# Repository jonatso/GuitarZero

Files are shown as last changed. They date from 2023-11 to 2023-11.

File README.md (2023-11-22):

## The idea

Our concept was a game inspired by Guitar Hero, where the player plays notes corresponding with notes ”falling down” a led matrix. Whether or not the player successfully plays the beat, determines which notes are actually being played. The player is meant to control the lead instrument, resulting in this instrument not being played whenever the player fails to hit a note. The backing instruments are always played. From the menu, the player has the option to select between a handful of songs of varying difficulty.

## Technical Summary

The MCU controls the song flow, input from the user and the visual output. The MCU sends data over SPI to the FPGA containing the required information about which notes the FPGA should play. The FPGA receives this data, and generates an audio signal using a set of pre-made instruments which contain one or more voices. This signal is further passed on to a DAC using I2S. Finally, the DAC outputs the audio to the onboard speaker or the audio jack.

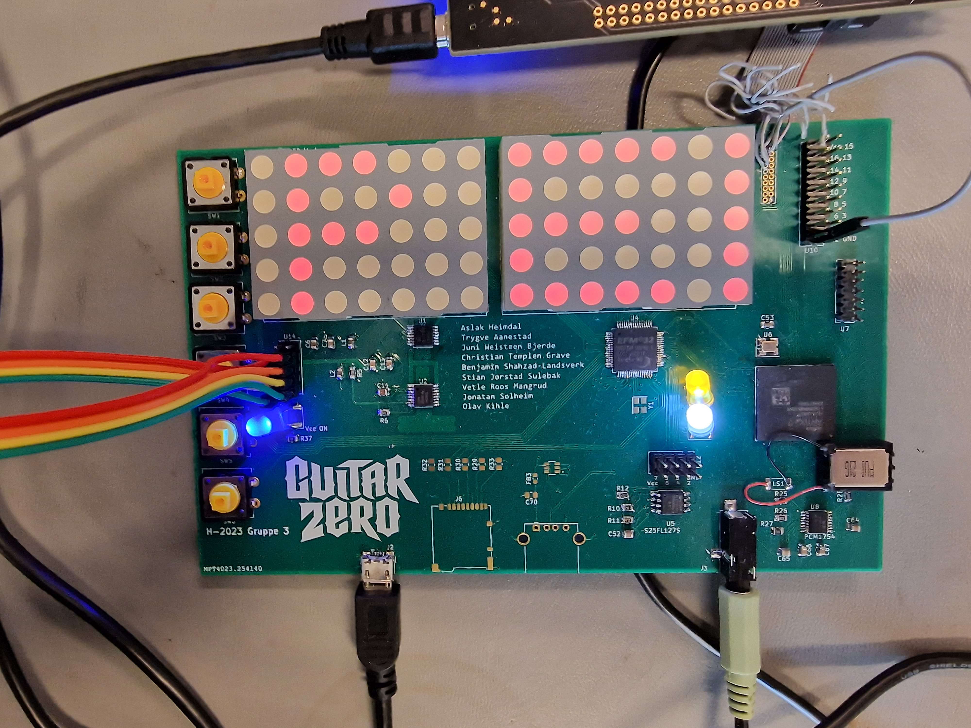
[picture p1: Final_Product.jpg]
Final Product


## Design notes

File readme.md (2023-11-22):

# GUITAR ZEEROOOOO MCU PROJECT

Bare minimum example, schmekket fra eksempelene:
- [USB Host Enum](https://github.com/EnergyMicro/EFM32GG_STK3700/tree/master/examples/usbhenum)
- [USB Host kbd](https://github.com/EnergyMicro/EFM32WG_DK3850/blob/master/examples/usbhhidkbd)

## Setup

- bruk linux eller WSL dings
- clone repoet
- i en annen dir, clone gecko sdk-en: [Gecko SDK](https://github.com/SiliconLabs/gecko_sdk), eller bare kopier hele sdk-en
- gå til cmake/GuitarZeroMCU.cmake og endre SDK_PATH til forrige step

## REQUIREMENTS

### ARM gcc toolchain
arm-none-eabi toolchain lagt til som binary executable i /usr/bin
- Last ned tarballen for linux [HER](https://launchpad.net/gcc-arm-embedded/+download) (jeg la den i /tmp)

```sh
# jeg pakket ut i /usr/share
sudo tar xjf gcc-arm-none-eabi-YOUR-VERSION.bz2 -C /usr/share/

# lager symolic links fra executablene til /usr/bin
sudo ln -s /usr/share/gcc-arm-none-eabi-YOUR-VERSION/bin/arm-none-eabi-gcc /usr/bin/arm-none-eabi-gcc 
sudo ln -s /usr/share/gcc-arm-none-eabi-YOUR-VERSION/bin/arm-none-eabi-g++ /usr/bin/arm-none-eabi-g++
sudo ln -s /usr/share/gcc-arm-none-eabi-YOUR-VERSION/bin/arm-none-eabi-gdb /usr/bin/arm-none-eabi-gdb
sudo ln -s /usr/share/gcc-arm-none-eabi-YOUR-VERSION/bin/arm-none-eabi-size /usr/bin/arm-none-eabi-size
sudo ln -s /usr/share/gcc-arm-none-eabi-YOUR-VERSION/bin/arm-none-eabi-objcopy /usr/bin/arm-none-eabi-objcopy
sudo ln -s /usr/share/gcc-arm-none-eabi-YOUR-VERSION/bin/arm-none-eabi-gcc-ranlib /usr/bin/arm-none-eabi-gcc-ranlib
sudo ln -s /usr/share/gcc-arm-none-eabi-YOUR-VERSION/bin/arm-none-eabi-ar /usr/bin/arm-none-eabi-ar

# check at de er lagt til i pathen
arm-none-eabi-gcc --version
arm-none-eabi-g++ --version
arm-none-eabi-gdb --version
arm-none-eabi-size --version
# osv ...
```

### CMAKE 3.25 eller nyere (Jeg brukte 3.27.7)
Man får ikke de nyere versjonene av Cmake med apt eller apt-get, så måtte installere manuelt. 
Jeg brukte denne guiden [HER](https://graspingtech.com/upgrade-cmake/), men den var meget slow...

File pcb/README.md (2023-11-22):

# TDT4295

Open GuitarZero.kicad_pro in kicad to open the projetc. Then click schematic ceditor to view the schematic.
Seperate schematic files for FPGA, PSU, MCU and DAC can be opened directly or via the GuitarZero.sch file.

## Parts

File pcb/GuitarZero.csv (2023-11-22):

Id | Designator | Footprint | Quantity | Designation | Supplier and ref
1 | FB3,FB1 | L_0603_1608Metric | 2 | FerriteBead
2 | J1 | USB_A_Stewart_SS-52100-001_Horizontal | 1 | USB_A
3 | C13,C7,C6,C12,C16,C73,C17 | C_0805_2012Metric | 7 | 22u
4 | J3 | Jack_3.5mm_CUI_SJ-3524-SMT_Horizontal | 1 | AudioJack3_SwitchT
5 | J6 | microSD_HC_Hirose_DM3BT-DSF-PEJS | 1 | Micro_SD_Card_Det_Hirose_DM3AT
6 | C11,C52,C53,C72,C55,C57,C5,C10,C59,C15,C19,C2,C60 | C_0805_2012Metric | 13 | 100n
7 | R29,R30,R27,R26,R25,R31,R28 | R_0805_2012Metric | 7 | 22
8 | D1,D2,D4 | LED_1812_4532Metric | 3 | LED
9 | J2 | USB_Micro-B_Amphenol_10103594-0001LF_Horizontal | 1 | USB_B_Micro
10 | U14 | PinHeader_2x05_P2.54mm_Vertical | 1 | Power_Jumpers
11 | U6 | Oscillator_SMD_Abracon_ASE-4Pin_3.2x2.5mm_HandSoldering | 1 | Oscillator
12 | C65,C66,C67,C64,C54,C9,C61,C58,C1,C18 | C_0805_2012Metric | 10 | 10u
13 | C70,C3,C35 | C_0805_2012Metric | 3 | 100u
14 | U3 | Xilinx_FTG256 | 1 | XC7A100T-FTG256
15 | SW3,SW2,SW6,SW5,SW1,SW4 | SW_CW_GPTS203211B | 6 | SW_Push
16 | R10 | R_0805_2012Metric | 1 | 2.4k
17 | U8 | SOP63P599X175-16N | 1 | PCM1754
18 | L1,L2 | L_0805_2012Metric | 2 | 1.5u
19 | J4 | PinSocket_2x10_P1.27mm_Vertical | 1 | MCU_Debug
20 | U5 | SOIC-8W_5.3x5.3mm_P1.27mm | 1 | S25FL127S
21 | U11,U13 | LED_TA20-11SRWA | 2 | 5x7 LED_matrix
22 | U4 | TQFP-64_10x10mm_P0.5mm | 1 | EFM32GG332
23 | Y1 | Crystal_SMD_Abracon_ABM8G-4Pin_3.2x2.5mm | 1 | Crystal_GND23
24 | R12,R11,R16,R15 | R_0805_2012Metric | 4 | 4.7k
25 | R5 | R_0805_2012Metric | 1 | 30.1k
26 | R37,R17,R34,R35 | R_0805_2012Metric | 4 | 330
27 | R33,R32 | R_0805_2012Metric | 2 | 47k
28 | R6,R8,R4 | R_0805_2012Metric | 3 | 22.1k
29 | U7 | PinSocket_2x07_P2.00mm_Vertical | 1 | FPGA_JTAG_Debug
30 | U9 | SOT95P280X145-6N | 1 | TPD_Current_Switch
31 | U2 | HTSSOP-16-1EP_4.4x5mm_P0.65mm_EP3x3mm | 1 | TSP54294
32 | LS1 | R_2010_5025Metric | 1 | Speaker
33 | U1 | TSSOP-14-1EP_4.4x5mm_P0.65mm | 1 | TPS54325
34 | U10 | PinHeader_2x09_P2.54mm_Vertical | 1 | FPGA_GPIO_Extra
35 | U12 | PinHeader_2x04_P2.54mm_Vertical | 1 | MCU_GPIO_Extra
36 | C31,C37,C30,C36,C51,C41,C34,C32,C33,C50,C42,C43,C29,C27,C49,C48,C28 | C_0603_1608Metric | 17 | 0.47u
37 | R1,R2 | R_0805_2012Metric | 2 | 100k
38 | R24,R21,R18,R23,R22 | R_0805_2012Metric | 5 | 100
39 | C56,C71,C4,C14 | C_0805_2012Metric | 4 | 1u
40 | R14,R13 | R_0805_2012Metric | 2 | 10k
41 | R3 | R_0805_2012Metric | 1 | 6.81k
42 | C24,C40,C23,C26,C47,C25,C22,C46,C21,C39 | C_0805_2012Metric | 10 | 4.7u
43 | C68,C69,C62,C63 | C_0805_2012Metric | 4 | 10n
44 | C45,C38,C44 | C_0805_2012Metric | 3 | 47u
45 | R7 | R_0805_2012Metric | 1 | 73.2k
46 | C20 | CAPMP7.6X4.3_1.9N_KEM | 1 | 330u
47 | R19,R20 | R_0805_2012Metric | 2 | 15
48 | R9 | R_0805_2012Metric | 1 | 1
49 | L3 | L_0805_2012Metric | 1 | 2.2u
50 | C8 | C_0805_2012Metric | 1 | 3.3n

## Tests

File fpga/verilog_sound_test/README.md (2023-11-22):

The files in this folder were used during the intial testing of the sound generating modules, before we started to use Vidado and a real FGPA. Many of the modules have been modified later, and is updated in the Vivado project files.
1. Install icarus-verilog (```brew install icarus-verilog``` for mac) + Python
2. ```pip install -r requirements.txt```
3. ```./run.sh```
4. ```./run_amplitude.sh```
5. ```./run_instrument.sh```

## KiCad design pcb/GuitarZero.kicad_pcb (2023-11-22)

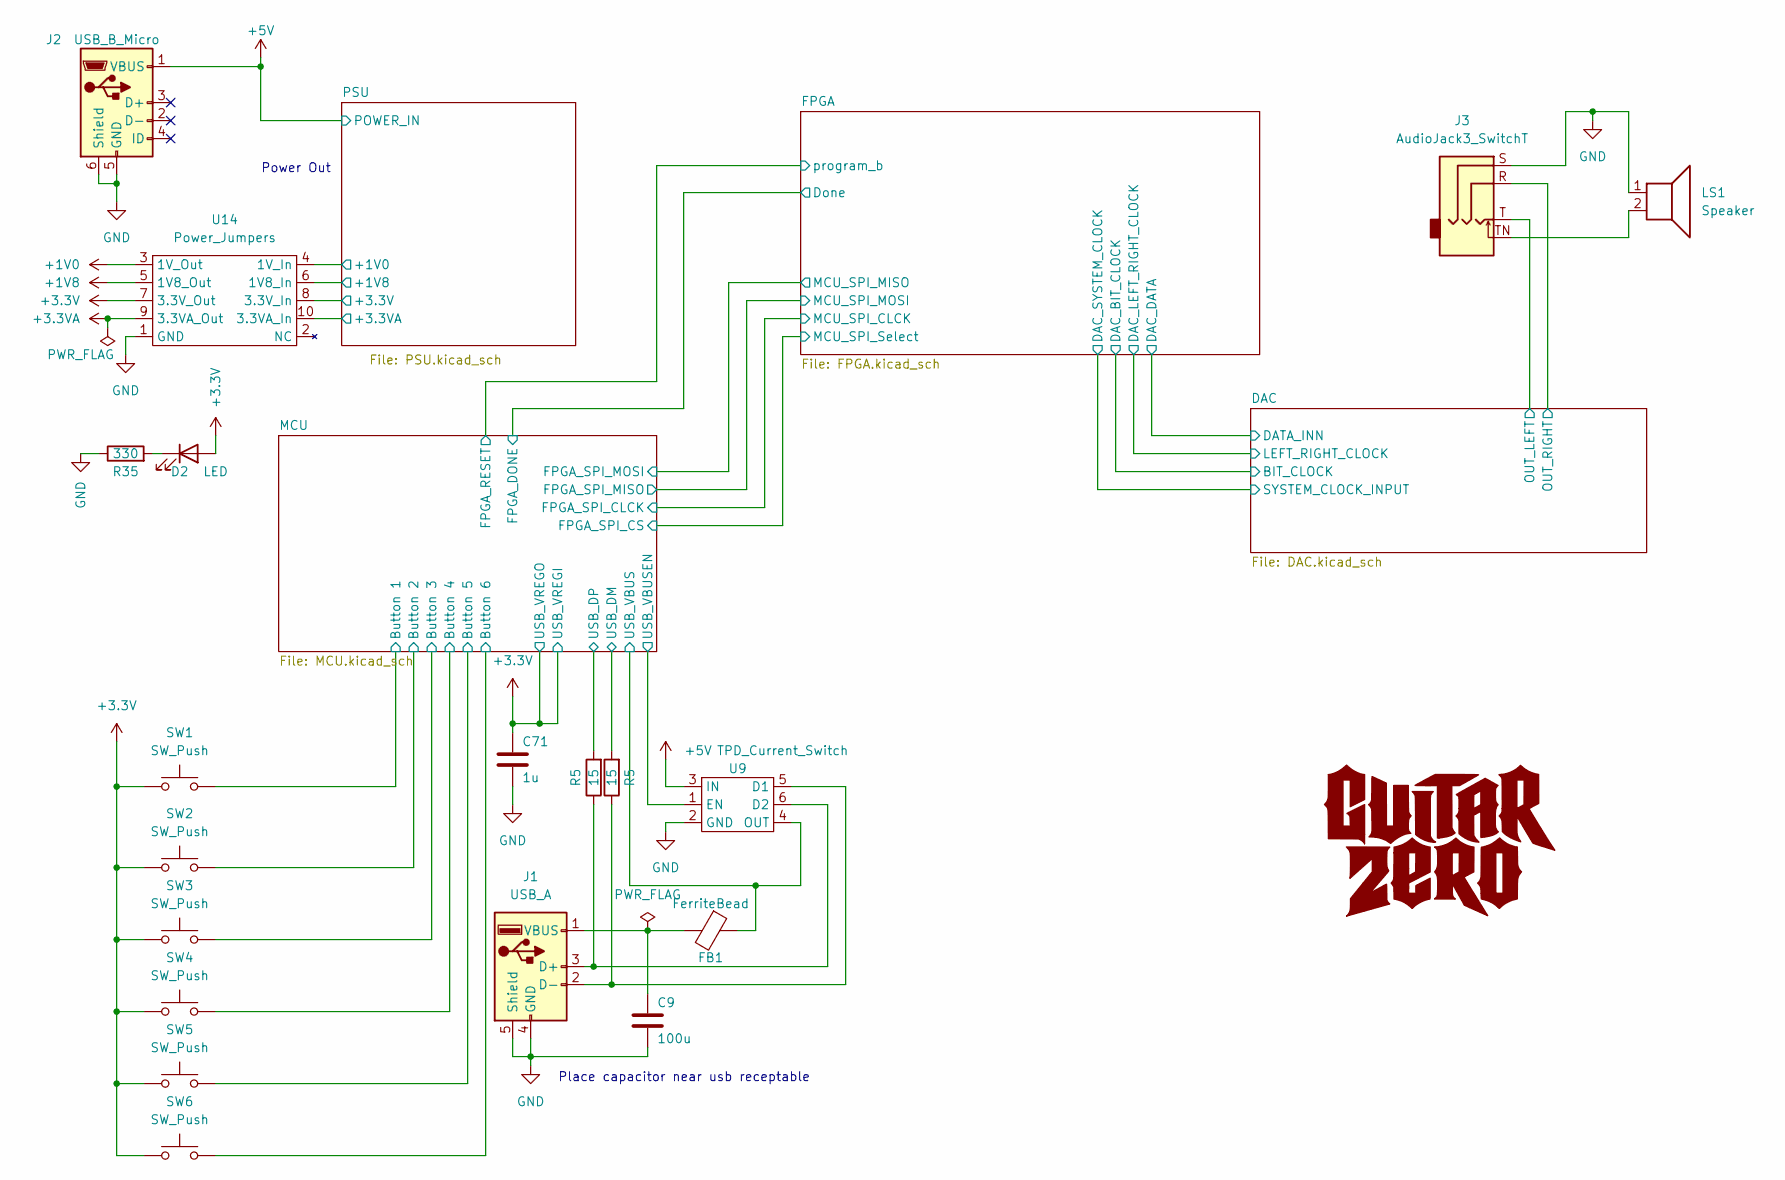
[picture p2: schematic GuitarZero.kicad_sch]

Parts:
C9: 100u; C_0805_2012Metric
C71: 1u; C_0805_2012Metric
D2: LED; LED_1812_4532Metric
FB1: FerriteBead; L_0603_1608Metric
J1: USB_A; USB_A_Stewart_SS-52100-001_Horizontal
J2: USB_B_Micro; USB_Micro-B_Amphenol_10103594-0001LF_Horizontal
J3: AudioJack3_SwitchT; Jack_3.5mm_CUI_SJ-3524-SMT_Horizontal
LS1: Speaker; R_2010_5025Metric
R5: 15; R_0805_2012Metric
R35: 330; R_0805_2012Metric
SW1, SW2, SW3, SW4, SW5, SW6: SW_Push; SW_CW_GPTS203211B
U9: TPD_Current_Switch; SOT95P280X145-6N
U14: Power_Jumpers; PinHeader_2x05_P2.54mm_Vertical

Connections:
+1V0: U14.3 (1V_Out); also elsewhere on the board
+1V8: U14.5 (1V8_Out); also elsewhere on the board
/DAC/OUT_LEFT: J3.T; also elsewhere on the board
/DAC/OUT_RIGHT: J3.R; also elsewhere on the board
/MCU/Button 1: SW1.2; also elsewhere on the board
/MCU/Button 2: SW2.2; also elsewhere on the board
/MCU/Button 3: SW3.2; also elsewhere on the board
/MCU/Button 4: SW4.2; also elsewhere on the board
/MCU/Button 5: SW5.2; also elsewhere on the board
/MCU/Button 6: SW6.2; also elsewhere on the board
/MCU/USB_VBUSEN: U9.1 (EN); also elsewhere on the board
/PSU/+1V0: U14.4 (1V_In); also elsewhere on the board
/PSU/+1V8: R5.2, U14.6 (1V8_In); also elsewhere on the board
/PSU/+3.3VA: U14.10 (3.3VA_In); also elsewhere on the board
unnamed: D2.1 (K), R35.2
unnamed: J3.TN, LS1.2

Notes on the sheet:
Power Out
Place capacitor near usb receptable

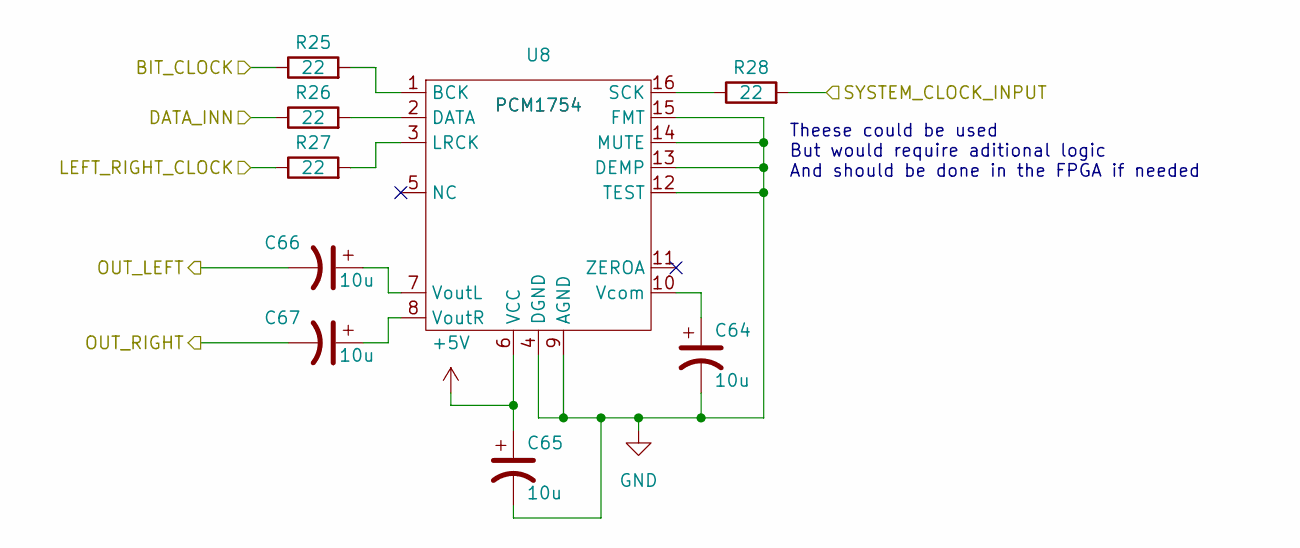
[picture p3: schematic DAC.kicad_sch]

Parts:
C64, C65, C66, C67: 10u; C_0805_2012Metric
R25, R26, R27, R28: 22; R_0805_2012Metric
U8: PCM1754; SOP63P599X175-16N

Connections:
/DAC/BIT_CLOCK: R25.1; also elsewhere on the board
/DAC/DATA_INN: R26.1; also elsewhere on the board
/DAC/LEFT_RIGHT_CLOCK: R27.1; also elsewhere on the board
/DAC/OUT_LEFT: C66.2; also elsewhere on the board
/DAC/OUT_RIGHT: C67.2; also elsewhere on the board
/DAC/SYSTEM_CLOCK_INPUT: R28.2; also elsewhere on the board
unnamed: R25.2, U8.1 (BCK)
unnamed: R26.2, U8.2 (DATA)
unnamed: R27.2, U8.3 (LRCK)
unnamed: R28.1, U8.16 (SCK)
unnamed: C64.1, U8.10 (Vcom)
unnamed: C66.1, U8.7 (VoutL)
unnamed: C67.1, U8.8 (VoutR)

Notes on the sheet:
Theese could be used But would require aditional logic And should be done in the FPGA if needed

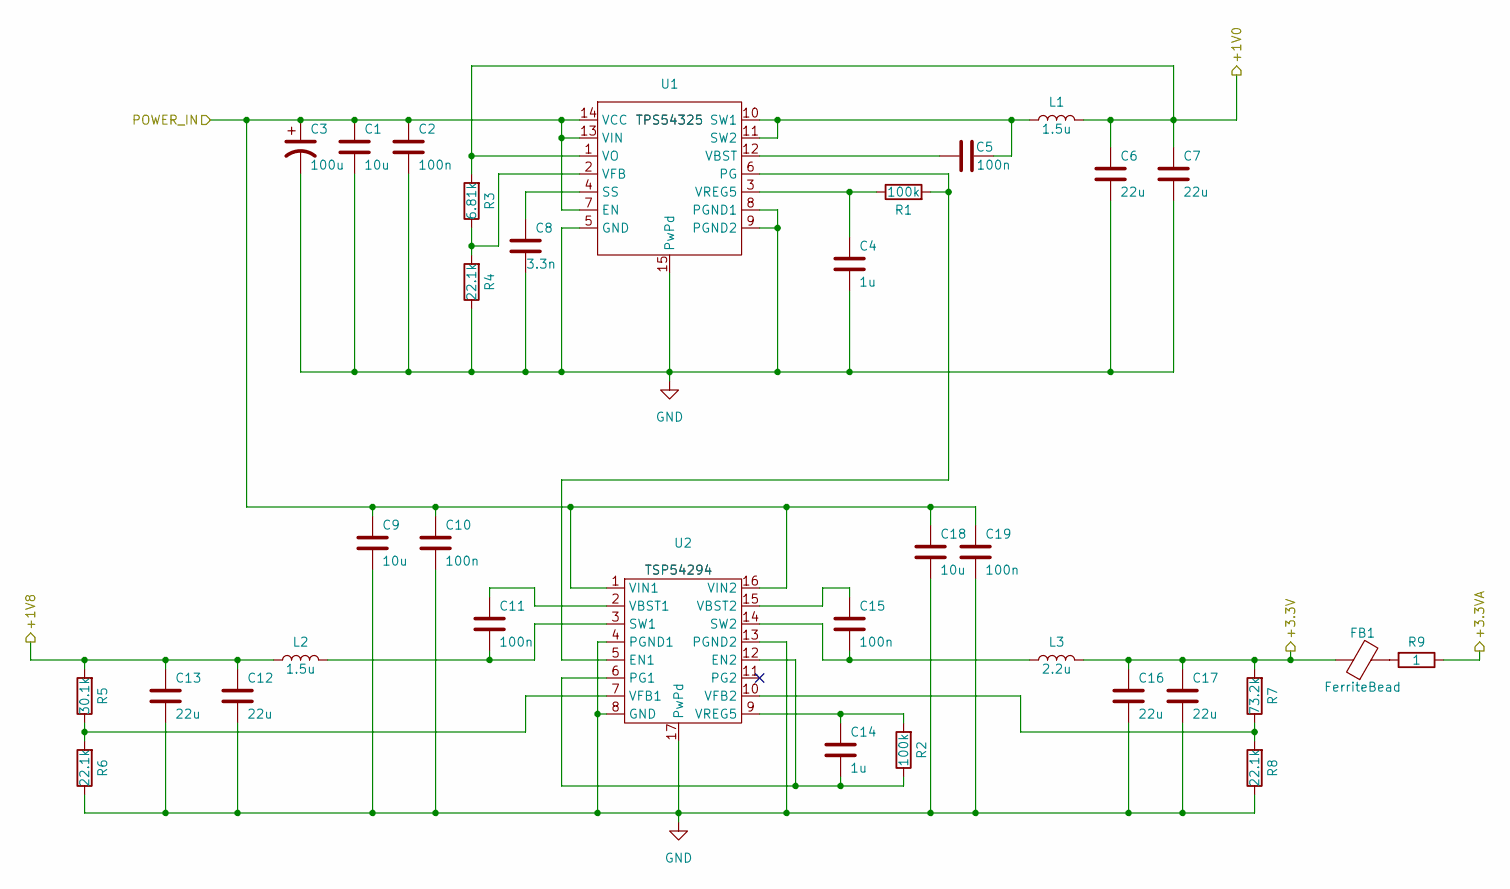
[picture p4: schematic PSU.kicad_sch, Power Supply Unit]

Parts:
C1, C9, C18: 10u; C_0805_2012Metric
C2, C5, C10, C11, C15, C19: 100n; C_0805_2012Metric
C3: 100u; C_0805_2012Metric
C4, C14: 1u; C_0805_2012Metric
C6, C7, C12, C13, C16, C17: 22u; C_0805_2012Metric
C8: 3.3n; C_0805_2012Metric
FB1: FerriteBead; L_0603_1608Metric
L1, L2: 1.5u; L_0805_2012Metric
L3: 2.2u; L_0805_2012Metric
R1, R2: 100k; R_0805_2012Metric
R3: 6.81k; R_0805_2012Metric
R4, R6, R8: 22.1k; R_0805_2012Metric
R5: 30.1k; R_0805_2012Metric
R7: 73.2k; R_0805_2012Metric
R9: 1; R_0805_2012Metric
U1: TPS54325; TSSOP-14-1EP_4.4x5mm_P0.65mm
U2: TSP54294; HTSSOP-16-1EP_4.4x5mm_P0.65mm_EP3x3mm

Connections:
/PSU/+1V0: C6.1, C7.1, L1.2, R3.2, U1.1 (VO); also elsewhere on the board
/PSU/+1V8: C12.1, C13.1, L2.1, R5.2; also elsewhere on the board
/PSU/+3.3VA: R9.1; also elsewhere on the board
unnamed: R1.2, U1.6 (PG), U2.5 (EN1)
unnamed: C8.1, U1.4 (SS)
unnamed: C5.1, L1.1, U1.10 (SW1), U1.11 (SW2)
unnamed: C5.2, U1.12 (VBST)
unnamed: R3.1, R4.2, U1.2 (VFB)
unnamed: C14.2, R2.1, U2.6 (PG1), U2.12 (EN2)
unnamed: C11.2, L2.2, U2.3 (SW1)
unnamed: C15.2, L3.1, U2.14 (SW2)
unnamed: C11.1, U2.2 (VBST1)
unnamed: C15.1, U2.15 (VBST2)
unnamed: R7.1, R8.2, U2.10 (VFB2)
unnamed: C14.1, R2.2, U2.9 (VREG5)

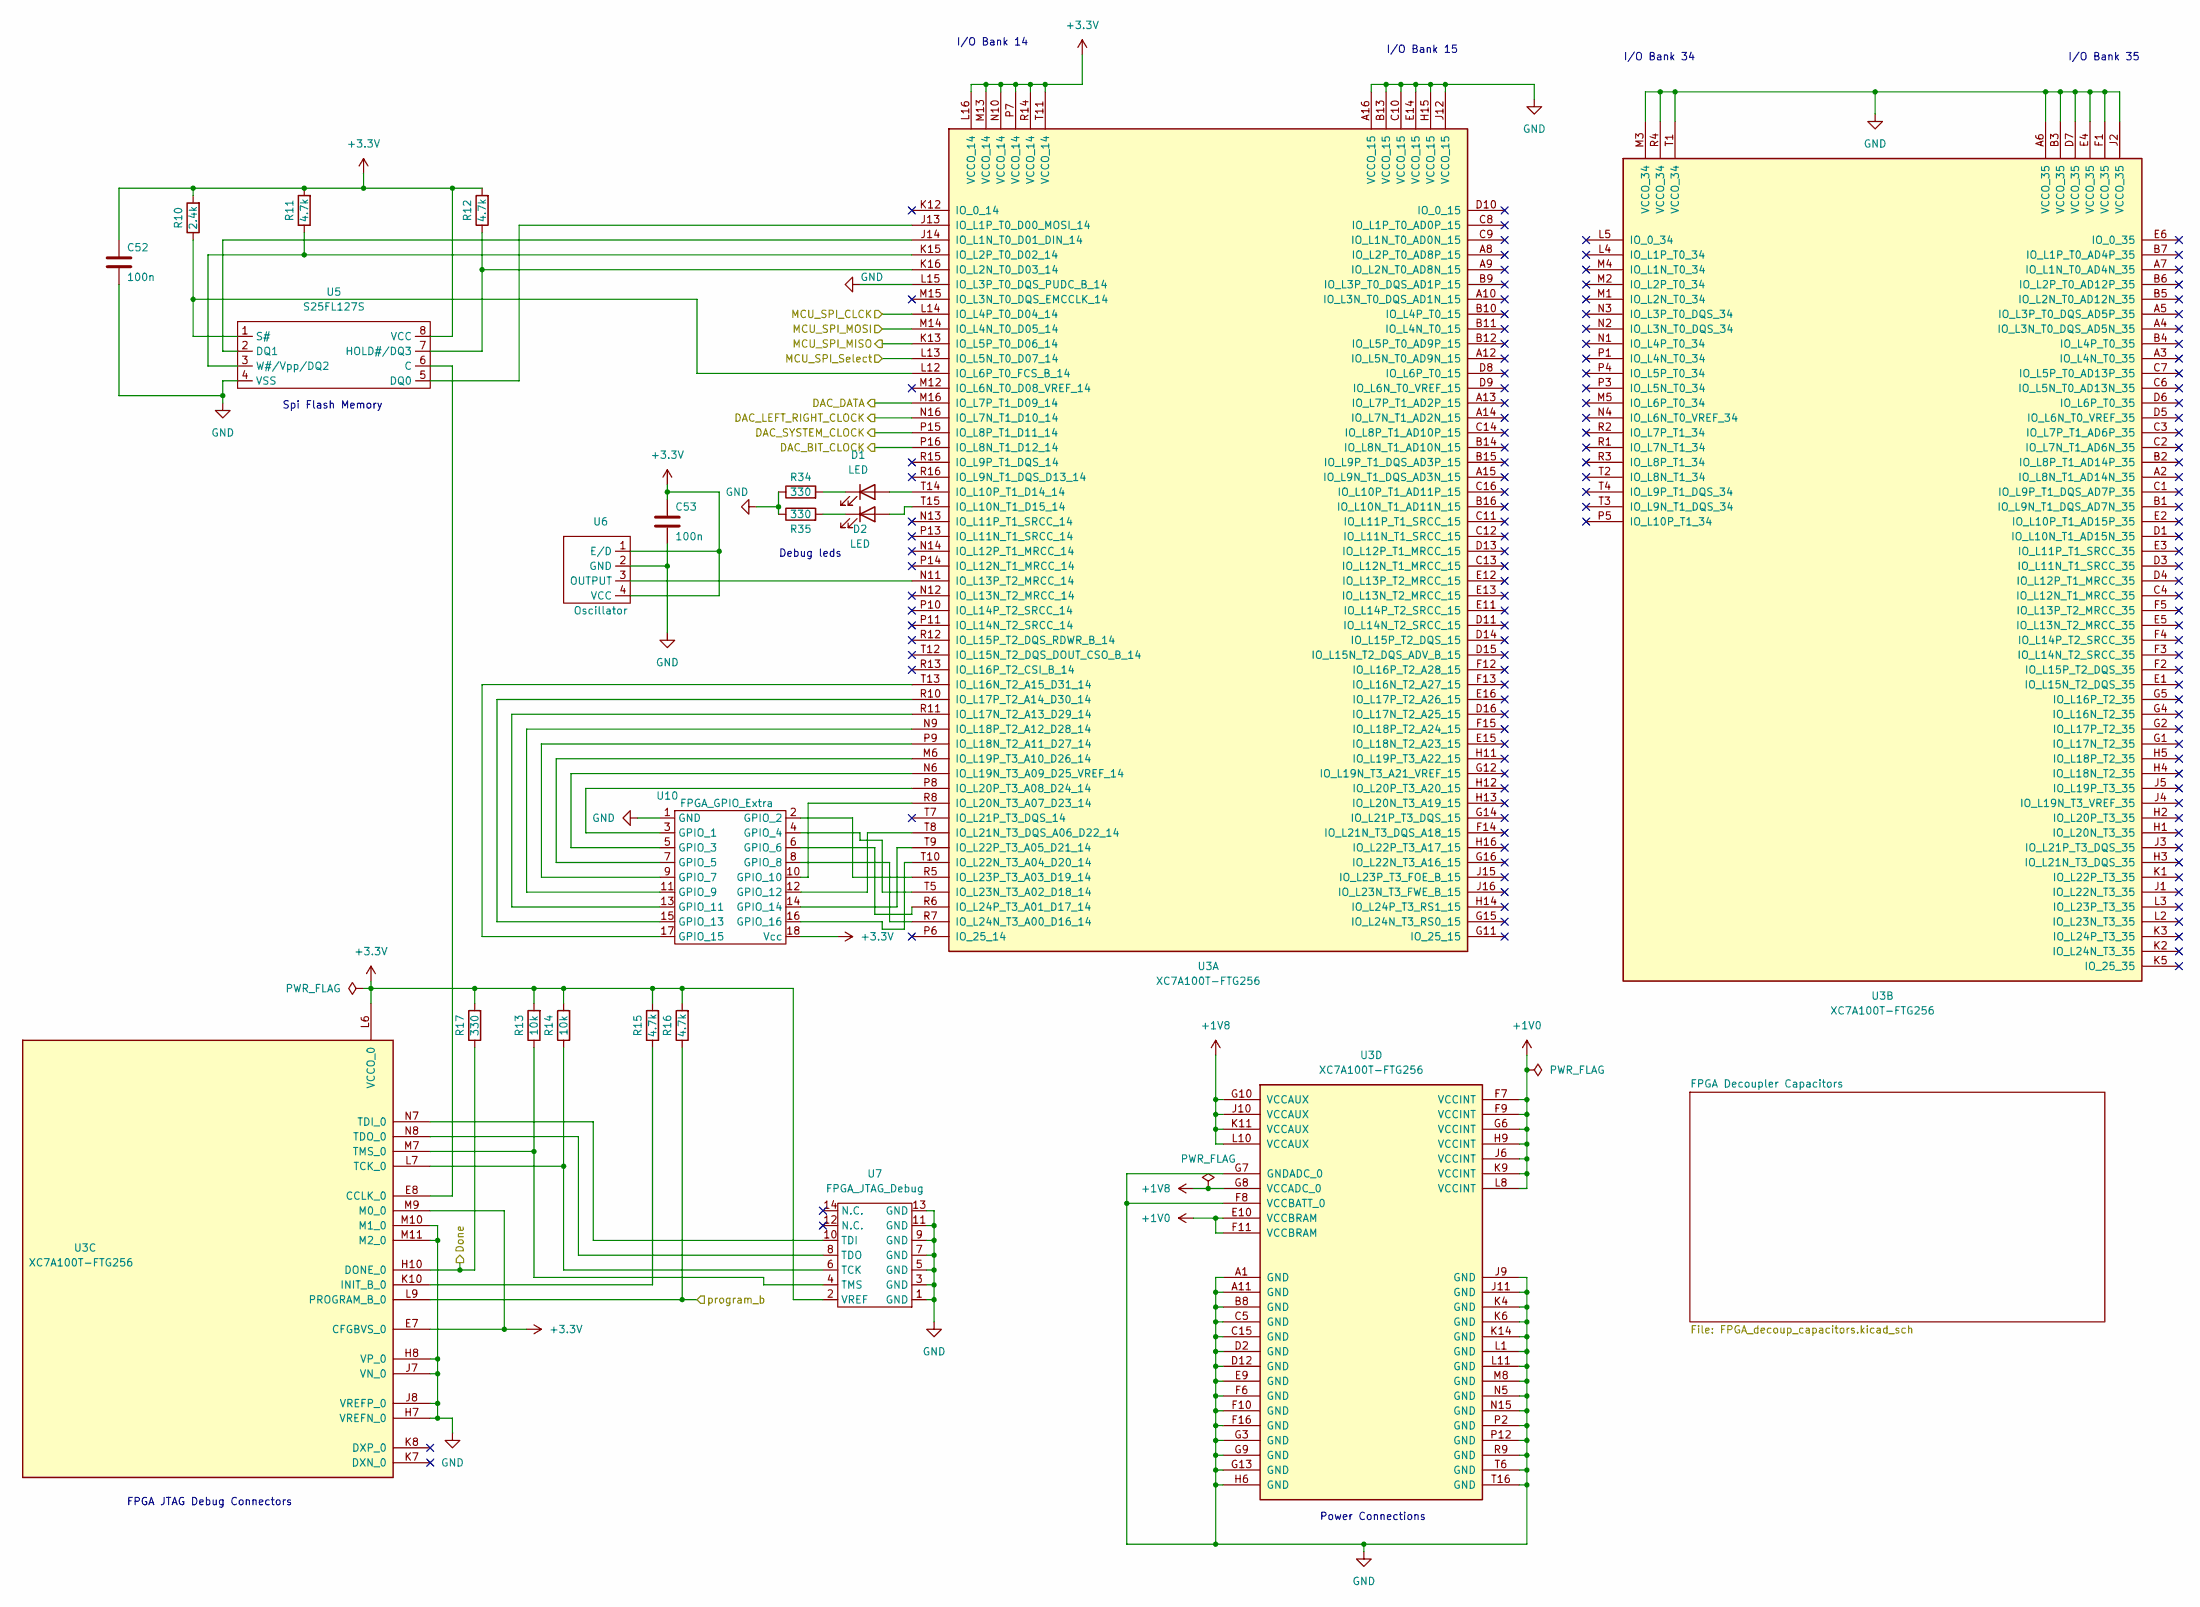
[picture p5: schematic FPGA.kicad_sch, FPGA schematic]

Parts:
C52, C53: 100n; C_0805_2012Metric
D1, D2: LED; LED_1812_4532Metric
R10: 2.4k; R_0805_2012Metric
R11, R12, R15, R16: 4.7k; R_0805_2012Metric
R13, R14: 10k; R_0805_2012Metric
R17, R34, R35: 330; R_0805_2012Metric
U3: XC7A100T-FTG256; Xilinx_FTG256
U5: S25FL127S; SOIC-8W_5.3x5.3mm_P1.27mm
U6: Oscillator; Oscillator_SMD_Abracon_ASE-4Pin_3.2x2.5mm_HandSoldering
U7: FPGA_JTAG_Debug; PinSocket_2x07_P2.00mm_Vertical
U10: FPGA_GPIO_Extra; PinHeader_2x09_P2.54mm_Vertical

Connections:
+1V0: U3.E10 (VCCBRAM), U3.F7 (VCCINT), U3.F9 (VCCINT), U3.F11 (VCCBRAM), U3.G6 (VCCINT), U3.H9 (VCCINT), U3.J6 (VCCINT), U3.K9 (VCCINT), U3.L8 (VCCINT); also elsewhere on the board
+1V8: U3.G8 (VCCADC_0), U3.G10 (VCCAUX), U3.J10 (VCCAUX), U3.K11 (VCCAUX), U3.L10 (VCCAUX); also elsewhere on the board
/DAC/BIT_CLOCK: U3.P16 (IO_L8N_T1_D12_14); also elsewhere on the board
/DAC/DATA_INN: U3.M16 (IO_L7P_T1_D09_14); also elsewhere on the board
/DAC/LEFT_RIGHT_CLOCK: U3.N16 (IO_L7N_T1_D10_14); also elsewhere on the board
/DAC/SYSTEM_CLOCK_INPUT: U3.P15 (IO_L8P_T1_D11_14); also elsewhere on the board
/FPGA/Done: R17.1, U3.H10 (DONE_0); also elsewhere on the board
/FPGA/MCU_SPI_CLCK: U3.L14 (IO_L4P_T0_D04_14); also elsewhere on the board
/FPGA/MCU_SPI_MISO: U3.K13 (IO_L5P_T0_D06_14); also elsewhere on the board
/FPGA/MCU_SPI_MOSI: U3.M14 (IO_L4N_T0_D05_14); also elsewhere on the board
/FPGA/MCU_SPI_Select: U3.L13 (IO_L5N_T0_D07_14); also elsewhere on the board
/FPGA/program_b: R16.1, U3.L9 (PROGRAM_B_0); also elsewhere on the board
unnamed: D1.2 (A), U3.T14 (IO_L10P_T1_D14_14)
unnamed: D1.1 (K), R34.2
unnamed: D2.1 (K), R35.2
unnamed: U3.J14 (IO_L1N_T0_D01_DIN_14), U5.2 (DQ1)
unnamed: U3.J13 (IO_L1P_T0_D00_MOSI_14), U5.5 (DQ0)
unnamed: R12.1, U3.K16 (IO_L2N_T0_D03_14), U5.7 (HOLD#/DQ3)
unnamed: R11.1, U3.K15 (IO_L2P_T0_D02_14), U5.3 (W#/Vpp/DQ2)
unnamed: R10.1, U3.L12 (IO_L6P_T0_FCS_B_14), U5.1 (S#)
unnamed: U3.N11 (IO_L13P_T2_MRCC_14), U6.3 (OUTPUT)
unnamed: U3.E8 (CCLK_0), U5.6 (C)
unnamed: R15.1, U3.K10 (INIT_B_0)
unnamed: R14.1, U3.L7 (TCK_0), U7.6 (TCK)
unnamed: U3.N7 (TDI_0), U7.10 (TDI)
unnamed: U3.N8 (TDO_0), U7.8 (TDO)
unnamed: R13.1, U3.M7 (TMS_0), U7.4 (TMS)
unnamed: U3.P8 (IO_L20P_T3_A08_D24_14), U10.3 (GPIO_1)
unnamed: U3.R5 (IO_L23P_T3_A03_D19_14), U10.2 (GPIO_2)
unnamed: U3.N6 (IO_L19N_T3_A09_D25_VREF_14), U10.5 (GPIO_3)
unnamed: U3.T5 (IO_L23N_T3_A02_D18_14), U10.4 (GPIO_4)
unnamed: U3.M6 (IO_L19P_T3_A10_D26_14), U10.7 (GPIO_5)
unnamed: U3.R6 (IO_L24P_T3_A01_D17_14), U10.6 (GPIO_6)
unnamed: U3.P9 (IO_L18N_T2_A11_D27_14), U10.9 (GPIO_7)
unnamed: U3.R7 (IO_L24N_T3_A00_D16_14), U10.8 (GPIO_8)
unnamed: U3.N9 (IO_L18P_T2_A12_D28_14), U10.11 (GPIO_9)
unnamed: U3.R8 (IO_L20N_T3_A07_D23_14), U10.10 (GPIO_10)
unnamed: U3.R11 (IO_L17N_T2_A13_D29_14), U10.13 (GPIO_11)
unnamed: U3.T8 (IO_L21N_T3_DQS_A06_D22_14), U10.12 (GPIO_12)
unnamed: U3.R10 (IO_L17P_T2_A14_D30_14), U10.15 (GPIO_13)
unnamed: U3.T9 (IO_L22P_T3_A05_D21_14), U10.14 (GPIO_14)
unnamed: U3.T13 (IO_L16N_T2_A15_D31_14), U10.17 (GPIO_15)
unnamed: U3.T10 (IO_L22N_T3_A04_D20_14), U10.16 (GPIO_16)

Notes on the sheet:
FPGA JTAG Debug Connectors
Spi Flash Memory
I/O Bank 35
I/O Bank 34
I/O Bank 15
Power Connections
Debug leds
I/O Bank 14

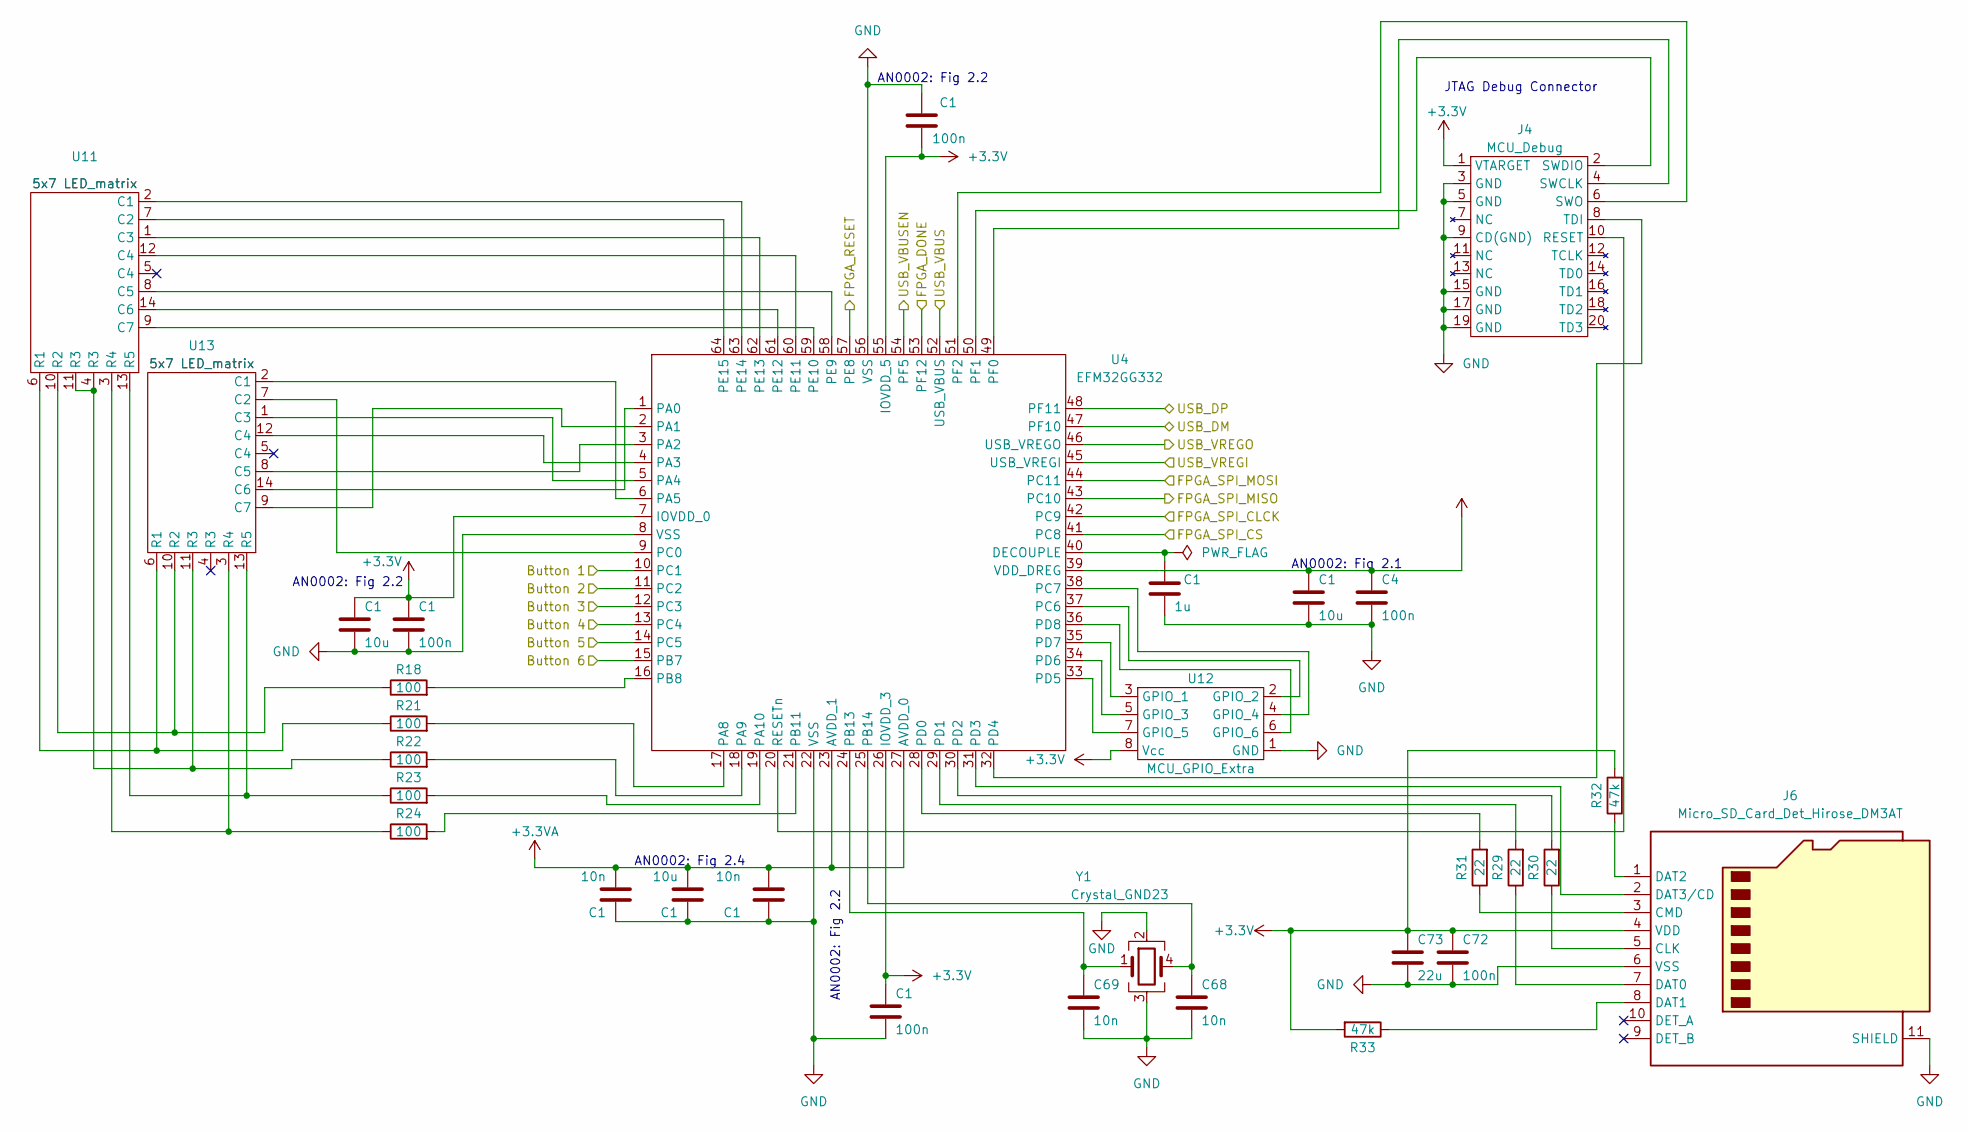
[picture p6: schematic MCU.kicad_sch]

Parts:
C1: 10u; C_0805_2012Metric
C4, C72: 100n; C_0805_2012Metric
C68, C69: 10n; C_0805_2012Metric
C73: 22u; C_0805_2012Metric
J4: MCU_Debug; PinSocket_2x10_P1.27mm_Vertical
J6: Micro_SD_Card_Det_Hirose_DM3AT; microSD_HC_Hirose_DM3BT-DSF-PEJS
R18, R21, R22, R23, R24: 100; R_0805_2012Metric
R29, R30, R31: 22; R_0805_2012Metric
R32, R33: 47k; R_0805_2012Metric
U4: EFM32GG332; TQFP-64_10x10mm_P0.5mm
U11, U13: 5x7 LED_matrix; LED_TA20-11SRWA
U12: MCU_GPIO_Extra; PinHeader_2x04_P2.54mm_Vertical
Y1: Crystal_GND23; Crystal_SMD_Abracon_ABM8G-4Pin_3.2x2.5mm

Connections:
/FPGA/Done: U4.53 (PF12); also elsewhere on the board
/FPGA/MCU_SPI_CLCK: U4.42 (PC9); also elsewhere on the board
/FPGA/MCU_SPI_MISO: U4.44 (PC11); also elsewhere on the board
/FPGA/MCU_SPI_MOSI: U4.43 (PC10); also elsewhere on the board
/FPGA/MCU_SPI_Select: U4.41 (PC8); also elsewhere on the board
/FPGA/program_b: U4.57 (PE8); also elsewhere on the board
/MCU/Button 1: U4.10 (PC1); also elsewhere on the board
/MCU/Button 2: U4.11 (PC2); also elsewhere on the board
/MCU/Button 3: U4.12 (PC3); also elsewhere on the board
/MCU/Button 4: U4.13 (PC4); also elsewhere on the board
/MCU/Button 5: U4.14 (PC5); also elsewhere on the board
/MCU/Button 6: U4.15 (PB7); also elsewhere on the board
/MCU/USB_DM: U4.47 (PF10); also elsewhere on the board
/MCU/USB_DP: U4.48 (PF11); also elsewhere on the board
/MCU/USB_VBUSEN: U4.54 (PF5); also elsewhere on the board
unnamed: J4.10 (RESET), U4.20 (RESETn)
unnamed: J4.4 (SWCLK), U4.49 (PF0)
unnamed: J4.2 (SWDIO), U4.50 (PF1)
unnamed: J4.6 (SWO), U4.51 (PF2)
unnamed: J4.8 (TDI), U4.32 (PD4)
unnamed: J6.5 (CLK), R30.1
unnamed: J6.3 (CMD), R31.1
unnamed: J6.7 (DAT0), R29.1
unnamed: J6.8 (DAT1), R33.1
unnamed: J6.1 (DAT2), R32.1
unnamed: J6.2 (DAT3/CD), U4.31 (PD3)
unnamed: R22.1, U11.4 (R3), U11.11 (R3), U13.11 (R3)
unnamed: U4.4 (PA3), U13.12 (C4)
unnamed: R21.2, U4.17 (PA8)
unnamed: R22.2, U4.18 (PA9)
unnamed: R23.2, U4.19 (PA10)
unnamed: R18.2, U4.16 (PB8)
unnamed: R24.2, U4.21 (PB11)
unnamed: C69.1, U4.24 (PB13), Y1.1
unnamed: C68.1, U4.25 (PB14), Y1.4
unnamed: R31.2, U4.28 (PD0)
unnamed: R29.2, U4.29 (PD1)
unnamed: R30.2, U4.30 (PD2)
unnamed: U4.60 (PE11), U11.12 (C4)
unnamed: U4.63 (PE14), U11.2 (C1)
unnamed: U4.64 (PE15), U11.7 (C2)
unnamed: U4.62 (PE13), U11.1 (C3)
unnamed: U4.58 (PE9), U11.8 (C5)
unnamed: U4.61 (PE12), U11.14 (C6)
unnamed: U4.59 (PE10), U11.9 (C7)
unnamed: R21.1, U11.6 (R1), U13.6 (R1)
unnamed: R18.1, U11.10 (R2), U13.10 (R2)
unnamed: R24.1, U11.3 (R4), U13.3 (R4)
unnamed: R23.1, U11.13 (R5), U13.13 (R5)
unnamed: U4.35 (PD7), U12.3 (GPIO_1)
unnamed: U4.37 (PC6), U12.2 (GPIO_2)
unnamed: U4.34 (PD6), U12.5 (GPIO_3)
unnamed: U4.38 (PC7), U12.4 (GPIO_4)
unnamed: U4.33 (PD5), U12.7 (GPIO_5)
unnamed: U4.36 (PD8), U12.6 (GPIO_6)
unnamed: U4.6 (PA5), U13.2 (C1)
unnamed: U4.9 (PC0), U13.7 (C2)
unnamed: U4.5 (PA4), U13.1 (C3)
unnamed: U4.3 (PA2), U13.8 (C5)
unnamed: U4.1 (PA0), U13.14 (C6)
unnamed: U4.2 (PA1), U13.9 (C7)

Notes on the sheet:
AN0002: Fig 2.2
AN0002: Fig 2.1
AN0002: Fig 2.4
JTAG Debug Connector

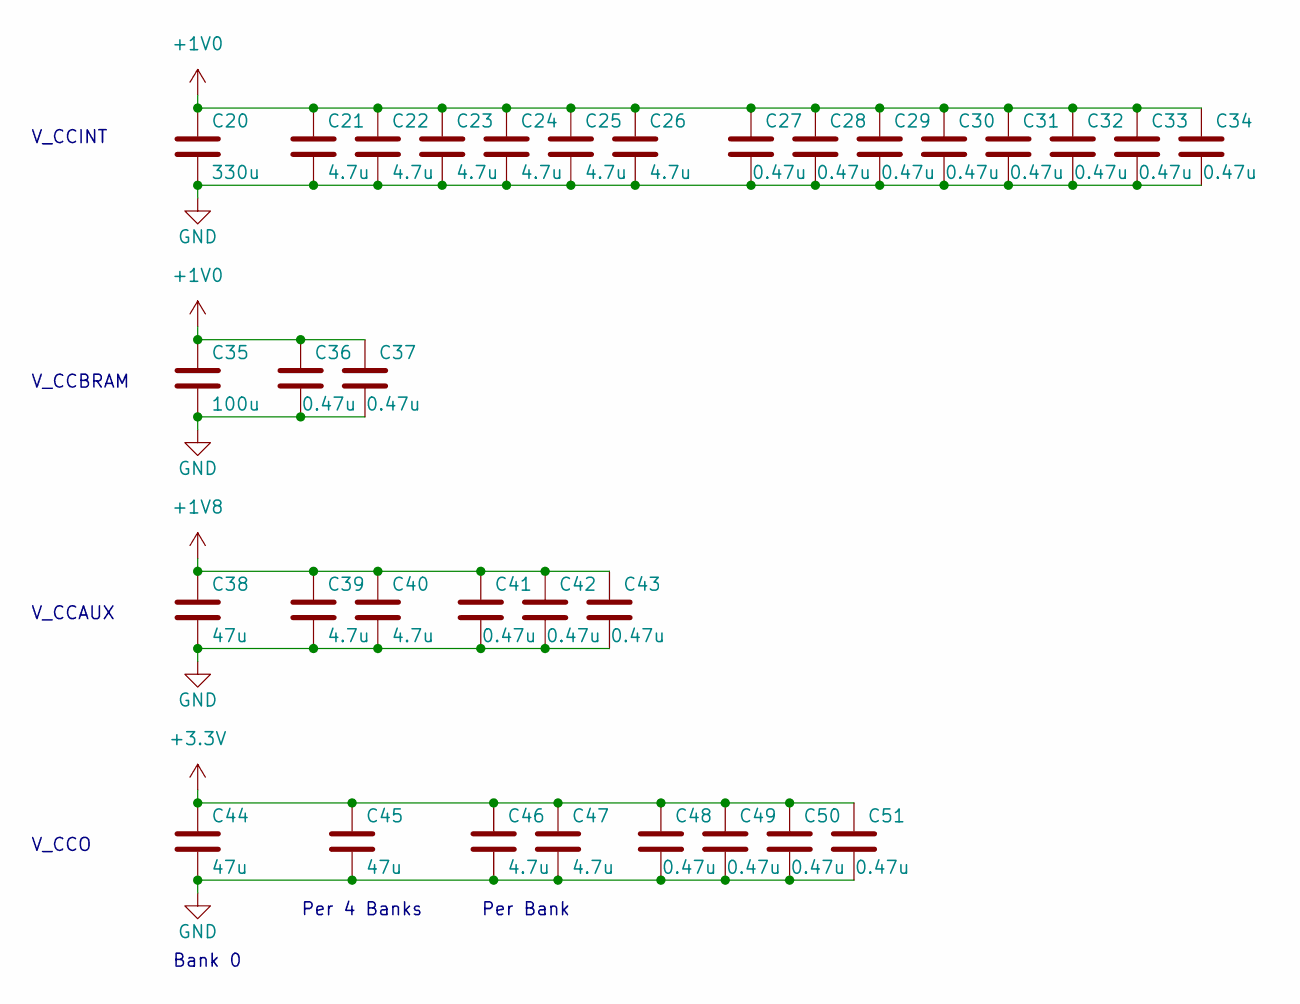
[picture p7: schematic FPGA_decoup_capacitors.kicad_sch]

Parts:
C20: 330u; CAPMP7.6X4.3_1.9N_KEM
C21, C22, C23, C24, C25, C26, C39, C40, C46, C47: 4.7u; C_0805_2012Metric
C27, C28, C29, C30, C31, C32, C33, C34, C36, C37, C41, C42, C43, C48, C49, C50, C51: 0.47u; C_0603_1608Metric
C35: 100u; C_0805_2012Metric
C38, C44, C45: 47u; C_0805_2012Metric

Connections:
+1V0: C20.1, C21.1, C22.1, C23.1, C24.1, C25.1, C26.1, C27.1, C28.1, C29.1, C30.1, C31.1, C32.1, C33.1, C34.1, C35.1, C36.1, C37.1; also elsewhere on the board
+1V8: C38.1, C39.1, C40.1, C41.1, C42.1, C43.1; also elsewhere on the board

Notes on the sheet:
Bank 0
V_CCO
V_CCAUX
V_CCINT
V_CCBRAM
Per 4 Banks
Per Bank

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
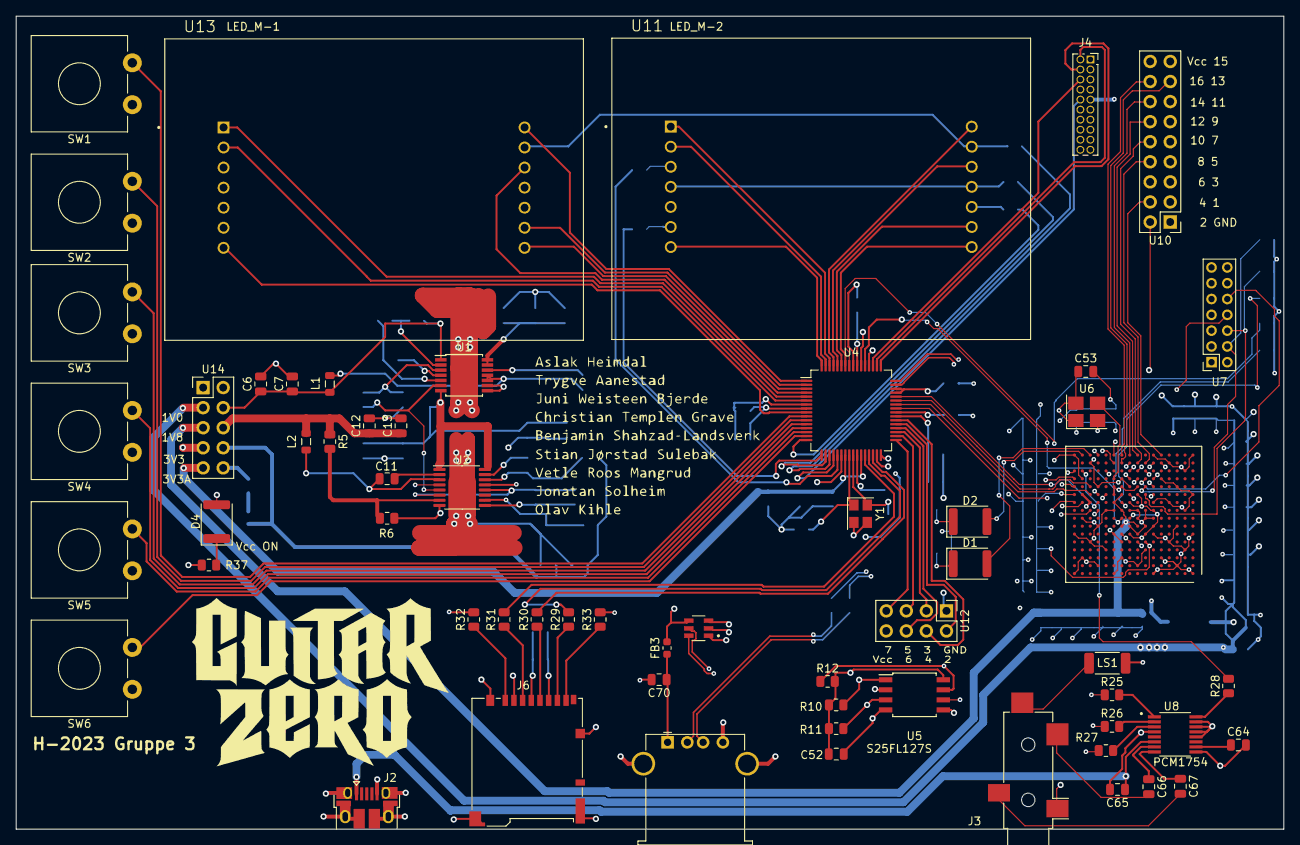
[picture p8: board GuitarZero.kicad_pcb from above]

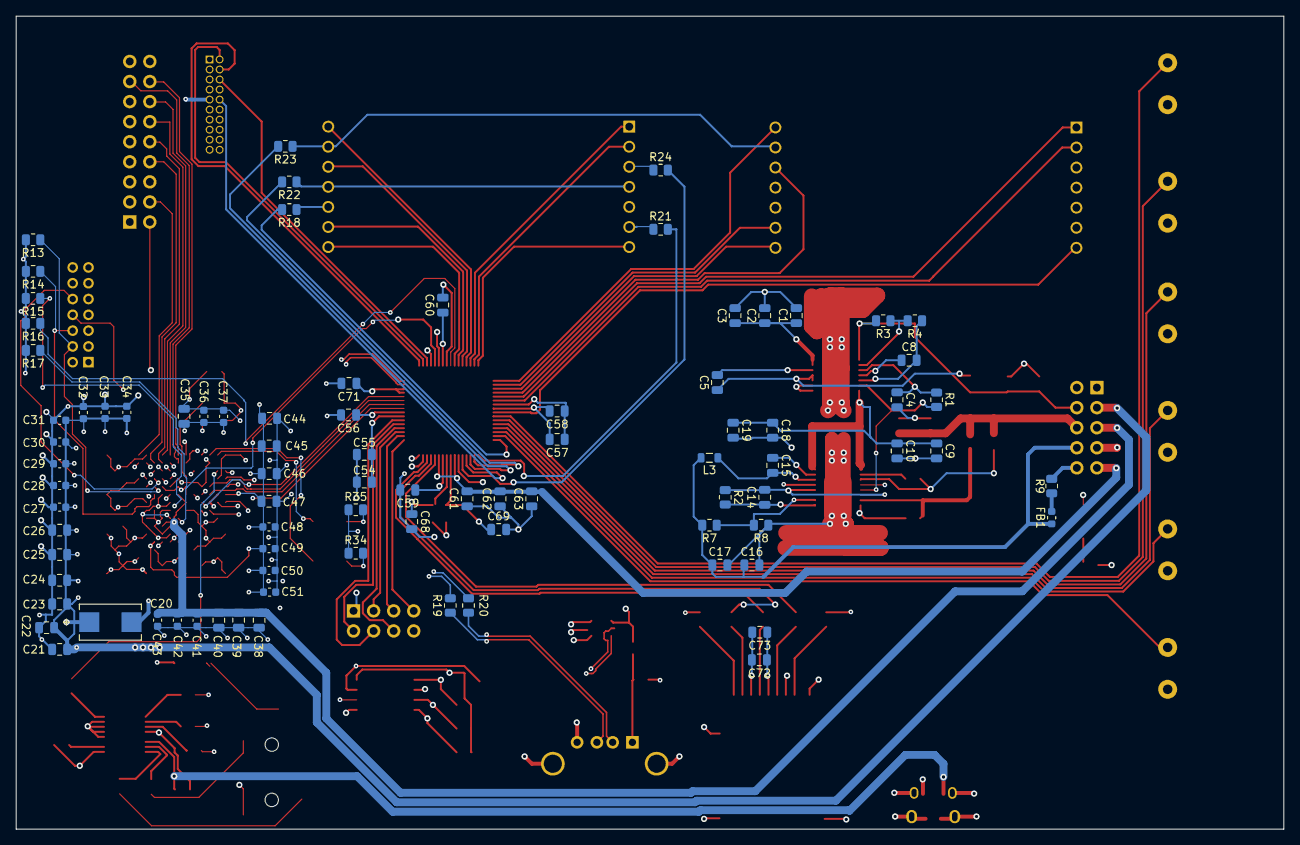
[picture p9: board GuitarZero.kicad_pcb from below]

Board: 6 copper layers, 160.4 x 102.9 mm, 145 parts (84 on the bottom side), 138 nets.

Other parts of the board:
C54, C58, C61: 10u; C_0805_2012Metric
C55, C57, C59, C60: 100n; C_0805_2012Metric
C56: 1u; C_0805_2012Metric
C62, C63: 10n; C_0805_2012Metric
C70: 100u; C_0805_2012Metric
D4: LED; LED_1812_4532Metric
FB3: FerriteBead; L_0603_1608Metric
H-2023 Gruppe 3: LOGO; Guitar_Zero_Logo
R19, R20: 15; R_0805_2012Metric
R37: 330; R_0805_2012Metric

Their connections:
/MCU/USB_DM: R20.2; also elsewhere on the board
/MCU/USB_DP: R19.2; also elsewhere on the board
unnamed: D4.1 (K), R37.2

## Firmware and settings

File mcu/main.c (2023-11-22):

/***************************************************************************//**
 * @file main.c
 * @brief main() function.
 *******************************************************************************
 * # License
 * <b>Copyright 2020 Silicon Laboratories Inc. www.silabs.com</b>
 *******************************************************************************
 *
 * The licensor of this software is Silicon Laboratories Inc. Your use of this
 * software is governed by the terms of Silicon Labs Master Software License
 * Agreement (MSLA) available at
 * www.silabs.com/about-us/legal/master-software-license-agreement. This
 * software is distributed to you in Source Code format and is governed by the
 * sections of the MSLA applicable to Source Code.
 *
 ******************************************************************************/
#include "sl_component_catalog.h"
#include "sl_system_init.h"
#include "app.h"
#if defined(SL_CATALOG_POWER_MANAGER_PRESENT)
#include "sl_power_manager.h"
#endif
#if defined(SL_CATALOG_KERNEL_PRESENT)
#include "sl_system_kernel.h"
#else // SL_CATALOG_KERNEL_PRESENT
#include "sl_system_process_action.h"
#endif // SL_CATALOG_KERNEL_PRESENT


int main(void)
{
  // Initialize Silicon Labs device, system, service(s) and protocol stack(s).
  // Note that if the kernel is present, processing task(s) will be created by
  // this call.
  sl_system_init();


  // Initialize the application. For example, create periodic timer(s) or
  // task(s) if the kernel is present.
  app_init();


#if defined(SL_CATALOG_KERNEL_PRESENT)
  // Start the kernel. Task(s) created in app_init() will start running.
  sl_system_kernel_start();
#else // SL_CATALOG_KERNEL_PRESENT
  while (1) {
    // Do not remove this call: Silicon Labs components process action routine
    // must be called from the super loop.
    sl_system_process_action();

    // Application process.
    app_process_action();

  }
#endif // SL_CATALOG_KERNEL_PRESENT
}

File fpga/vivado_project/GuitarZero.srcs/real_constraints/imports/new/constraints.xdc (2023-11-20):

# GuitarZero constraints file made some help from our great friend Geir

# SPI-Boot-Flash
# set_property -dict { PACKAGE_PIN J13   IOSTANDARD LVCMOS33 } [get_ports { boot_dq0 }];
# set_property -dict { PACKAGE_PIN J14   IOSTANDARD LVCMOS33 } [get_ports { boot_dq1 }];
# set_property -dict { PACKAGE_PIN K15   IOSTANDARD LVCMOS33 } [get_ports { boot_dq2 }];
# set_property -dict { PACKAGE_PIN K16   IOSTANDARD LVCMOS33 } [get_ports { boot_dq3 }];
# set_property -dict { PACKAGE_PIN L12   IOSTANDARD LVCMOS33 } [get_ports { boot_s_hash }]; # is called S#
# set_property -dict { PACKAGE_PIN E8    IOSTANDARD LVCMOS33 } [get_ports { boot_c }];

#MCU-SPI - mosi and miso are switched! connected wrong in the schematics...
set_property -dict {PACKAGE_PIN L14 IOSTANDARD LVCMOS33} [get_ports mcu_clck]
set_property -dict {PACKAGE_PIN K13 IOSTANDARD LVCMOS33} [get_ports mcu_mosi]
set_property -dict {PACKAGE_PIN M14 IOSTANDARD LVCMOS33} [get_ports mcu_miso]
set_property -dict {PACKAGE_PIN L13 IOSTANDARD LVCMOS33} [get_ports mcu_cs]

# DAC-I2S
set_property -dict {PACKAGE_PIN M16 IOSTANDARD LVCMOS33} [get_ports dac_data]
set_property -dict {PACKAGE_PIN N16 IOSTANDARD LVCMOS33} [get_ports dac_lrclck]
set_property -dict {PACKAGE_PIN P15 IOSTANDARD LVCMOS33} [get_ports dac_sysclck]
set_property -dict {PACKAGE_PIN P16 IOSTANDARD LVCMOS33} [get_ports dac_bclck]

# DEBUG-LEDS
set_property -dict {PACKAGE_PIN T14 IOSTANDARD LVCMOS33} [get_ports led1]
set_property -dict {PACKAGE_PIN T15 IOSTANDARD LVCMOS33} [get_ports led2]

# Oscillator
set_property -dict {PACKAGE_PIN N11 IOSTANDARD LVCMOS33} [get_ports osc]
create_clock -period 50.000 -name osc_clk -add [get_ports osc]

# # DEBUG-CONNECTOR
# set_property -dict { PACKAGE_PIN N7    IOSTANDARD LVCMOS33 } [get_ports { tdi }];
# set_property -dict { PACKAGE_PIN N8    IOSTANDARD LVCMOS33 } [get_ports { tdo }];
# set_property -dict { PACKAGE_PIN M7    IOSTANDARD LVCMOS33 } [get_ports { tms }];
# set_property -dict { PACKAGE_PIN L7    IOSTANDARD LVCMOS33 } [get_ports { tck }];
# set_property -dict { PACKAGE_PIN M9    IOSTANDARD LVCMOS33 } [get_ports { vcc_debug1 }];
# set_property -dict { PACKAGE_PIN E7    IOSTANDARD LVCMOS33 } [get_ports { vcc_debug2 }];

# # GPIO
#set_property -dict { PACKAGE_PIN T13   IOSTANDARD LVCMOS33 } [get_ports { gpio_15 }];
#set_property -dict { PACKAGE_PIN R10   IOSTANDARD LVCMOS33 } [get_ports { gpio_13 }];
set_property -dict {PACKAGE_PIN R11 IOSTANDARD LVCMOS33} [get_ports gpio_11]
set_property -dict {PACKAGE_PIN N9 IOSTANDARD LVCMOS33} [get_ports gpio_9]
set_property -dict {PACKAGE_PIN P9 IOSTANDARD LVCMOS33} [get_ports gpio_7]
set_property -dict { PACKAGE_PIN M6    IOSTANDARD LVCMOS33 } [get_ports { gpio_5 }];
set_property -dict { PACKAGE_PIN B6    IOSTANDARD LVCMOS33 } [get_ports { gpio_3 }];
set_property -dict { PACKAGE_PIN P8    IOSTANDARD LVCMOS33 } [get_ports { gpio_1 }];
set_property -dict { PACKAGE_PIN R5    IOSTANDARD LVCMOS33 } [get_ports { gpio_2 }];
set_property -dict { PACKAGE_PIN T5    IOSTANDARD LVCMOS33 } [get_ports { gpio_4 }];
set_property -dict {PACKAGE_PIN R6 IOSTANDARD LVCMOS33} [get_ports gpio_6]
set_property -dict {PACKAGE_PIN R7 IOSTANDARD LVCMOS33} [get_ports gpio_8]
set_property -dict {PACKAGE_PIN R8 IOSTANDARD LVCMOS33} [get_ports gpio_10]
set_property -dict {PACKAGE_PIN T8 IOSTANDARD LVCMOS33} [get_ports gpio_12]
# set_property -dict { PACKAGE_PIN T9    IOSTANDARD LVCMOS33 } [get_ports { gpio_14 }];
# set_property -dict { PACKAGE_PIN T10   IOSTANDARD LVCMOS33 } [get_ports { gpio_16 }];

##################
# created from
##################

#SPI-Boot-Flash
#J13 - DQ0
#J14 - DQ1
#K15 - DQ2
#K16 - DQ3
#L12 - S#
#E8 -> C
#
#MCU-SPI
#L14 - CLCK
#M14 - MOSI
#K13 - MISO
#L13 - CS
#
#DAC-I2S
#M16 - DATA
#N16 - LRCLCK
#P15 - SYSCLCK
#P16 - BCLCK
#
#DEBUG-LEDS
#T14
#T15
#
#Oscillator
#N11
#
#DEBUG-CONNECTOR
#N7 - TDI
#N8 - TDO
#M7 - TMS
#L7 - TCK
#M9 - Vcc
#E7 - Vcc
#
#GPIO
#T13 - GPIO_15
#R10 - GPIO_13
#R11 - GPIO_11
#N9  - GPIO_9
#P9  - GPIO_7
#M6  - GPIO_5
#B6  - GPIO_3
#P8  - GPIO_1
#R5  - GPIO_2
#T5  - GPIO_ 4
#R6  - GPIO_6
#R7  - GPIO_8
#R8  - GPIO_10
#T8  - GPIO_12
#T9  - GPIO_14
#T10 - GPIO_16

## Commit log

2023-09-07 cooler demo song 🤯
2023-10-02 working ewma filter
2023-10-03 fixed dout to not cut out adsr r part, cooler demo
2023-10-18 fixes cmake config, the project compiles!
    [redirect_printf.c]
2023-10-30 Lag funksjoner for å displaye banen på led-matrisen
2023-10-31 implements basic spi support
2023-10-31 lineend printf
2023-11-01 cleanup spi impl
2023-11-10 Send konstant 0b1111111111111111 på SPI
2023-11-16 fix: timer config and sl_sleep_manager beeing turned on (not good)
    [app.c, main.c]
2023-11-20 Buttons made
2023-11-20 feat: adds controls vars and functions for reading button inputs
2023-11-22 Add PCB contents
    [DAC.kicad_sch, FPGA.kicad_sch, FPGA_decoup_capacitors.kicad_sch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]
2023-11-22 rename part 2
    [DAC.kicad_sch, FPGA.kicad_sch, FPGA_decoup_capacitors.kicad_sch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]
